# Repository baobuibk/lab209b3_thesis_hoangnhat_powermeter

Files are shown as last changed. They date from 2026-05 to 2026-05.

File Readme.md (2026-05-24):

# Power Meter Thesis — Project Overview

This repository contains the design, firmware, and dashboard for a low-cost embedded Power Meter developed as a thesis project.

Summary
- Objective: design and implement a compact, accurate power-meter device with real-time web monitoring and data logging.
- Scope: PCB designs (Altium), STM32 firmware (ADC sampling, signal processing, Modbus RS-485), and a Node.js dashboard for visualization.

Quick links
- Video demo: see [Video/Readme.md](Video/Readme.md)
- Dashboard: see [Dashboard](Dashboard)
- Firmware & source: see [Code](Code)
- Schematics & PCBs: see [Altium](Altium)

Getting started
- Build firmware: follow the CMake/Toolchain files in `Code/` and use an ARM toolchain (GCC `arm-none-eabi`).
- Run dashboard: in `Dashboard/` run `npm install` then `node server.js` to start the web UI.

Contributions & contact
- This repo contains thesis artifacts and reference implementations. Open an issue or contact the author for questions or collaboration.

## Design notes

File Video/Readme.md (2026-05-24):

# Video: Power Meter Demo

This folder contains a demo video for the Power Meter project. You can view or download the video from Dropbox:

- Dropbox link: https://www.dropbox.com/scl/fo/yewsmshvbbur9p4b5wdh0/ADq9qIouHD3EygoDCD3pfRs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

If the link does not open, copy-paste it into your browser.

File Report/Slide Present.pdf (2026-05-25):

### TRƯỜNG ĐẠI HỌC BÁCH KHOA THÀNH PHỐ HỒ CHÍ MINH KHOA ĐIỆN – ĐIỆN TỬ BỘ MÔN CUNG CẤP ĐIỆN

## ĐỒ ÁN TỐT NGHIỆP

### THIẾT KẾ THIẾT BỊ ĐỒNG HỒ ĐO ĐIỆN BA PHA

(Design of a Real-Time Monitoring Device for Three-Phase Electrical Parameters)

GVHD: ThS. Bùi Quốc Bảo
TS. Phạm Minh Đức
SVTH : Hoàng Sỹ Nhất 211915

TP. Hồ Chí Minh, 09/10/2025

Nội dung | FR

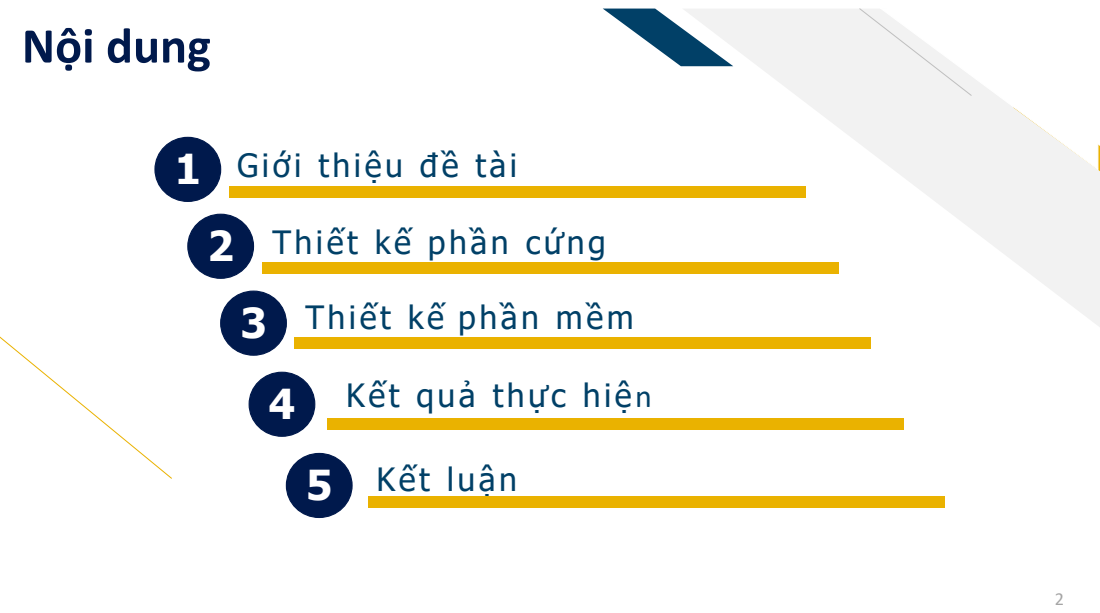
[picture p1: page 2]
Kết luận

Giới thiệu đề tài

Thiết kế phần cứng

Thiết kế phần mềm

Kết quả thực hiện

1. Giới thiệu đề tài | FR

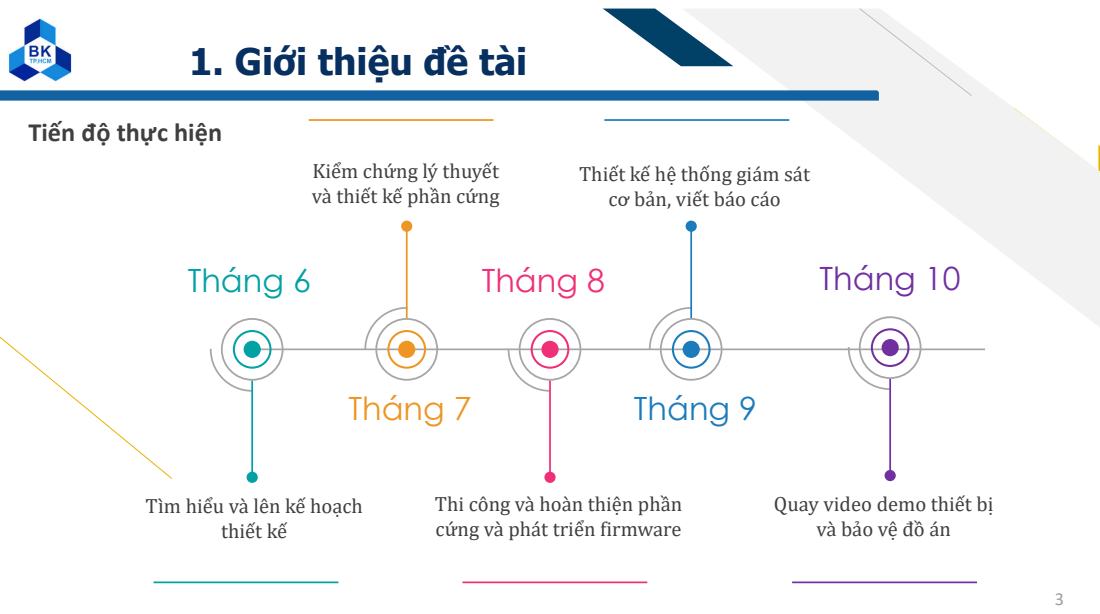
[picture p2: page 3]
Tháng 6; thiết kế; Tháng 7; Tháng 8; Tháng 9; Tháng 10

Tiến độ thực hiện

Kiểm chứng lý thuyết
và thiết kế phần cứng

Thiết kế hệ thống giám sát
cơ bản, viết báo cáo

Tìm hiểu và lên kế hoạch

Thi công và hoàn thiện phần
cứng và phát triển firmware

Quay video demo thiết bị
và bảo vệ đồ án

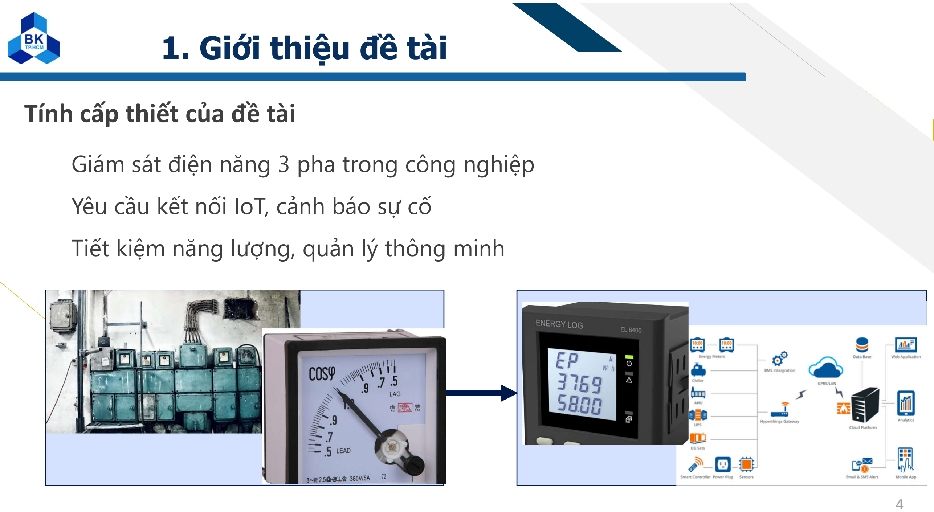
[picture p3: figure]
1. Giới thiệu đề tài; Tính cấp thiết của đề tài; Yêu cầu kết nối IoT, cảnh báo sự cố

Giám sát điện năng 3 pha trong công nghiệp

Tiết kiệm năng lượng, quản lý thông minh

1. Giới thiệu đề tài | FR

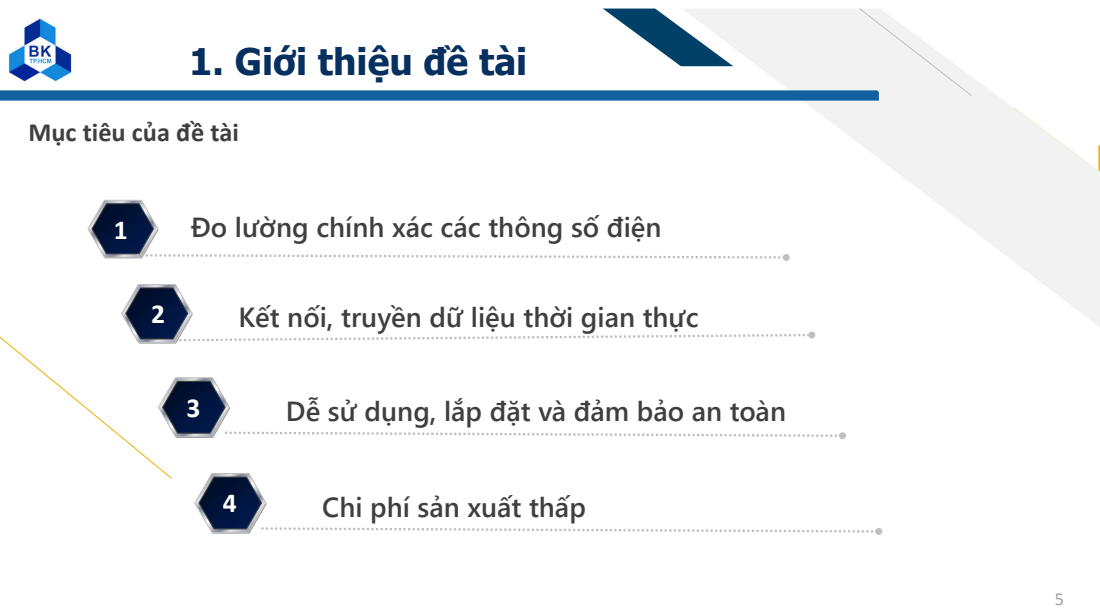
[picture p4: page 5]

Mục tiêu của đề tài

1 Đo lường chính xác các thông số điện

2 Kết nối, truyền dữ liệu thời gian thực

3 Dễ sử dụng, lắp đặt và đảm bảo an toàn

4 Chi phí sản xuất thấp

Bo thử nghiệm | Thiết bị đo phiên bản đầu tiên

2. Thiết kế phần cứng | FR

Sơ đồ khối tổng quát thiết bị

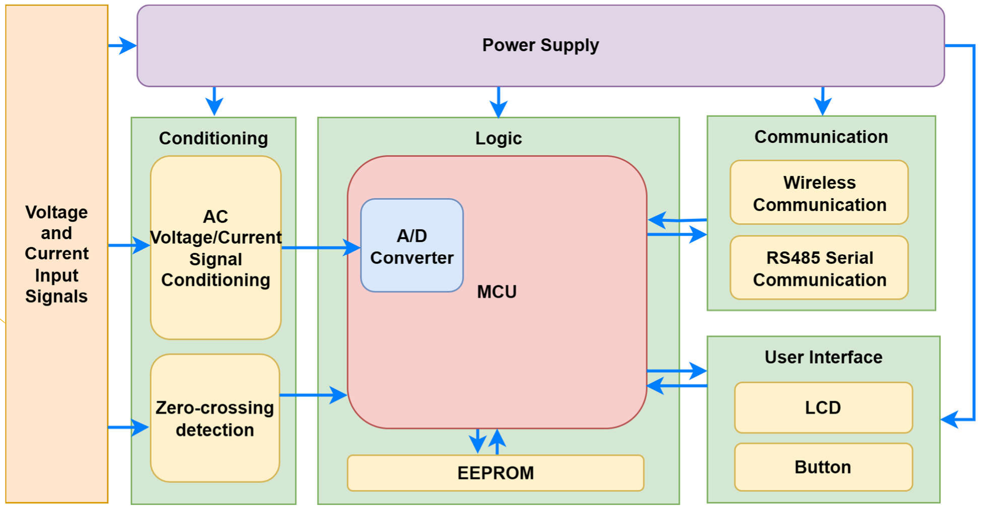
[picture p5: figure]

FR

## 2. Thiết kế phần cứng

8

Bo mạch dưới | Bo mạch trên

FR

## 2. Thiết kế phần cứng

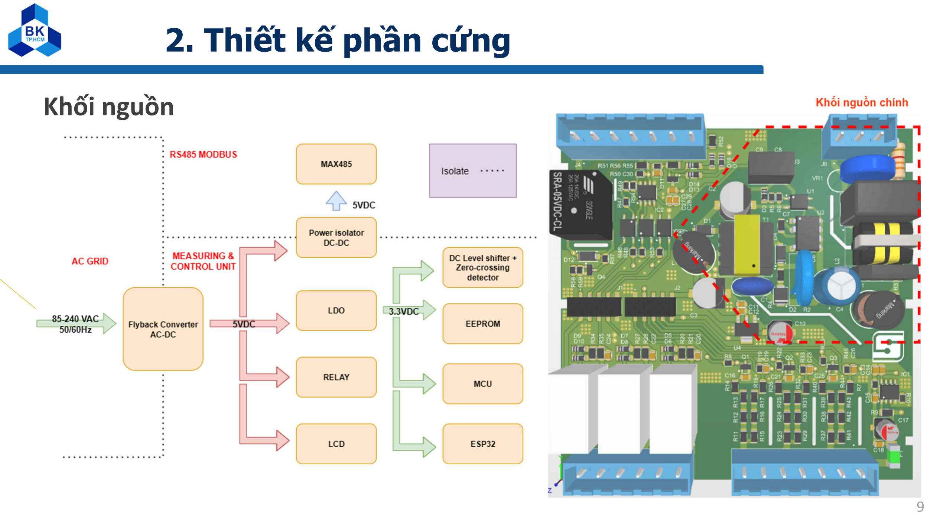
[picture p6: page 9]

9

### Khối nguồn

FR

## 2. Thiết kế phần cứng

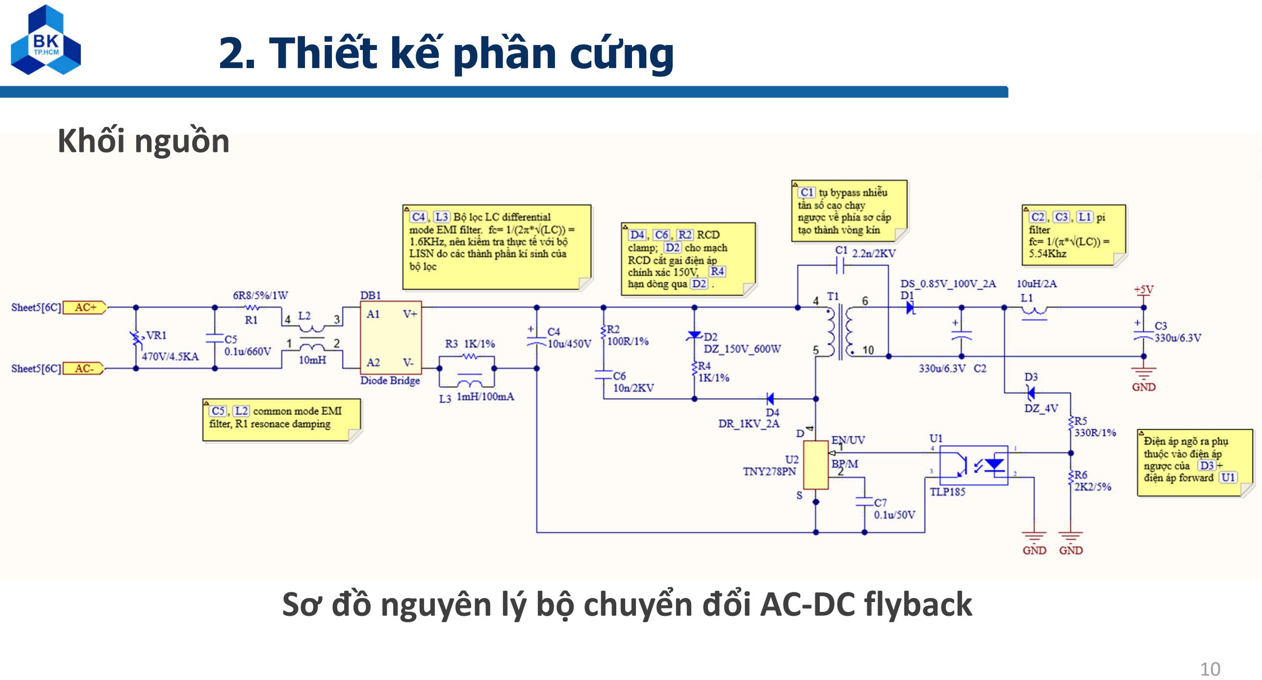
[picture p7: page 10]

10

### Khối nguồn

### Sơ đồ nguyên lý bộ chuyển đổi AC-DC flyback

FR

## 2. Thiết kế phần cứng

11

### Khối xử lý điện áp và dòng

Sơ đồ tín hiệu điện áp và tín hiệu sau xử lý

FR

## 2. Thiết kế phần cứng

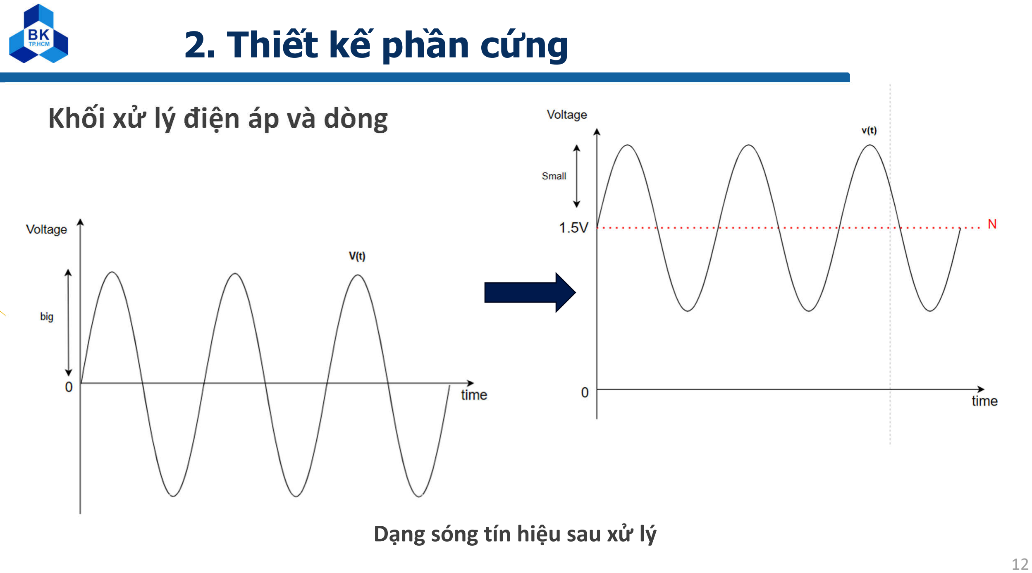
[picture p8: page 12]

12

### Khối xử lý điện áp và dòng

Dạng sóng tín hiệu sau xử lý

FR

## 2. Thiết kế phần cứng

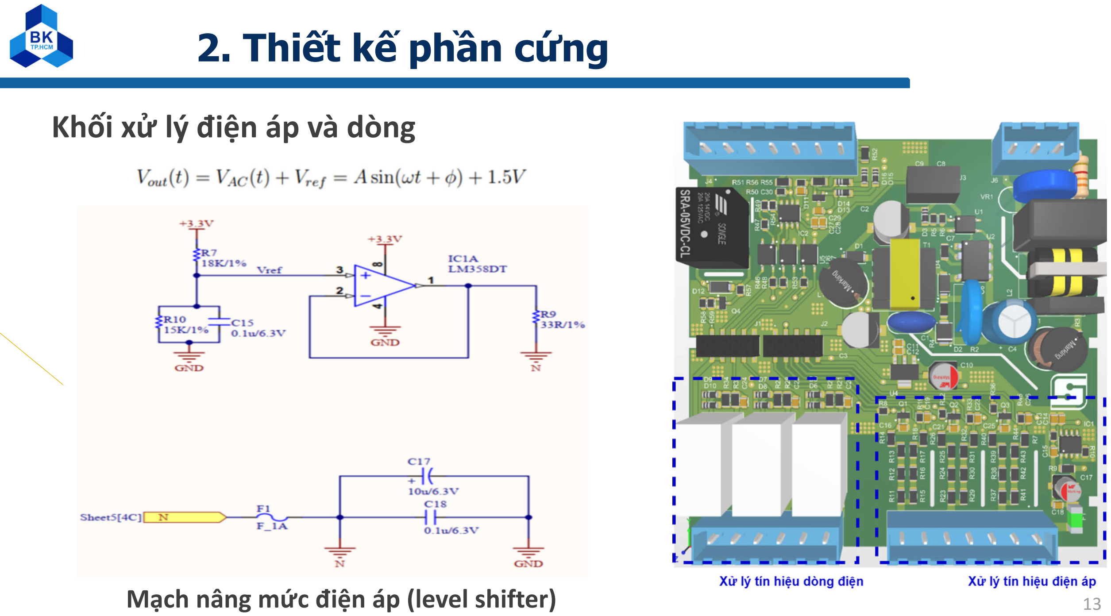
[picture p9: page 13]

13

### Khối xử lý điện áp và dòng

Mạch nâng mức điện áp (level shifter)

FR

## 2. Thiết kế phần cứng

14

### Khối xử lý điện áp và dòng

Mạch xử lý tín hiệu dòng điện

FR

## 2. Thiết kế phần cứng

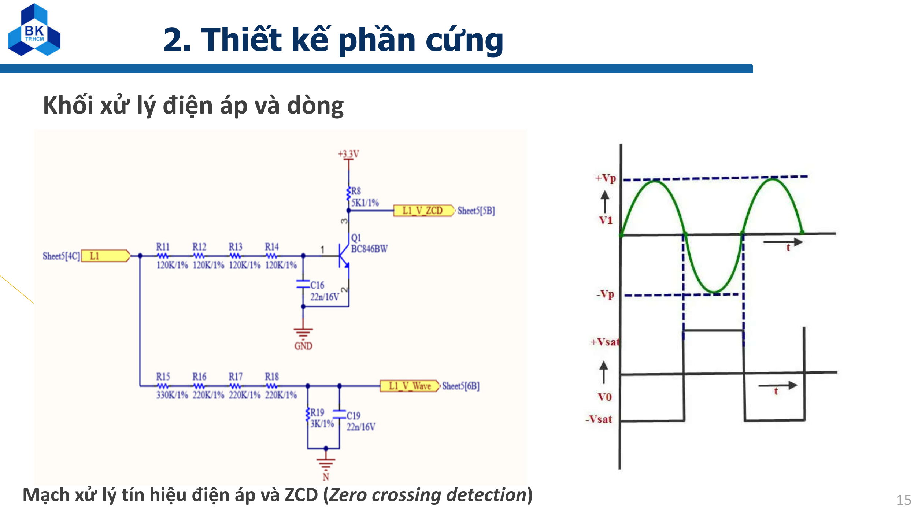
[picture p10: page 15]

15

### Khối xử lý điện áp và dòng

Mạch xử lý tín hiệu điện áp và ZCD (Zero crossing detection)

FR

## 2. Thiết kế phần cứng

16

### Khối giao tiếp RS485 và Relay

FR

## 2. Thiết kế phần cứng

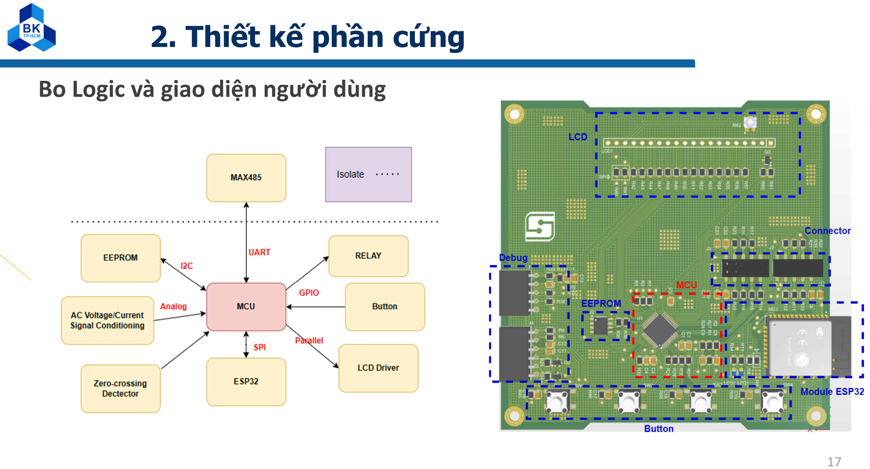
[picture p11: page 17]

17

### Bo Logic và giao diện người dùng

FR

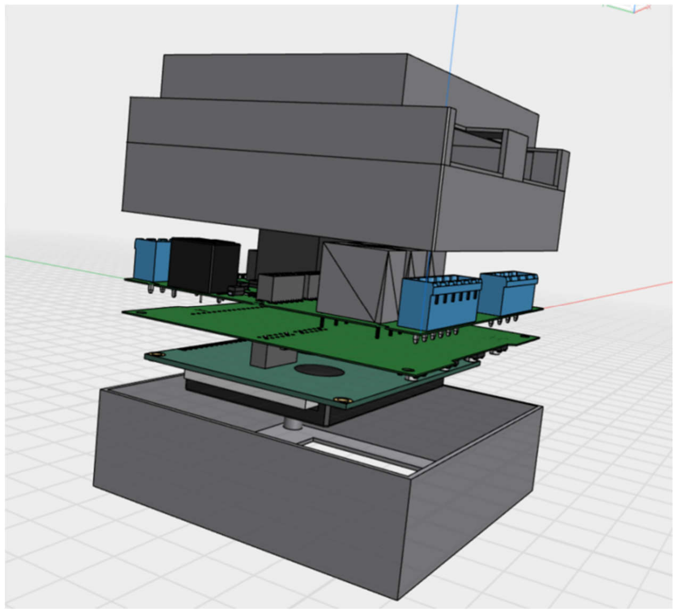
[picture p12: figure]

18

## 2. Thiết kế phần cứng

### Thiết kế vỏ hộp

AC Grid → STM32 → ESP32 → MQTT Broker → Web Dashboard.

FR

## 3. Thiết kế phần mềm

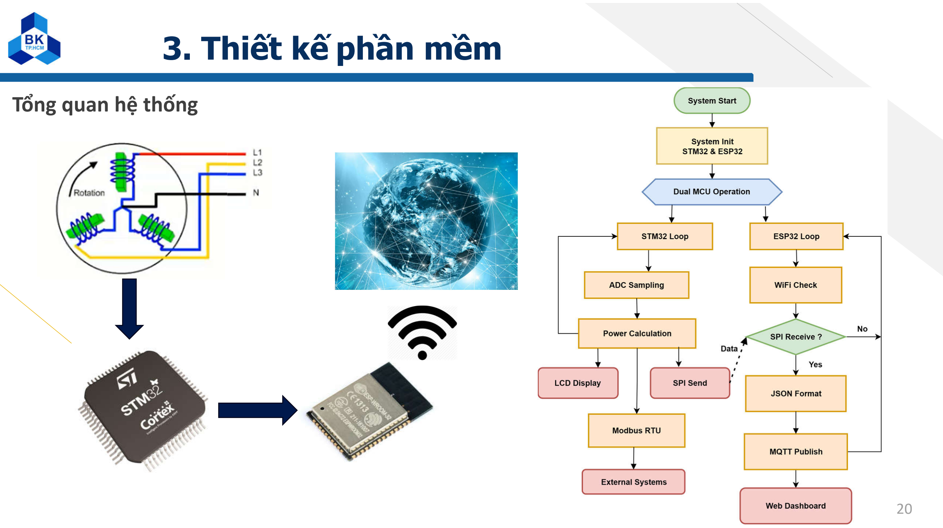
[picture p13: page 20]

20

Tổng quan hệ thống

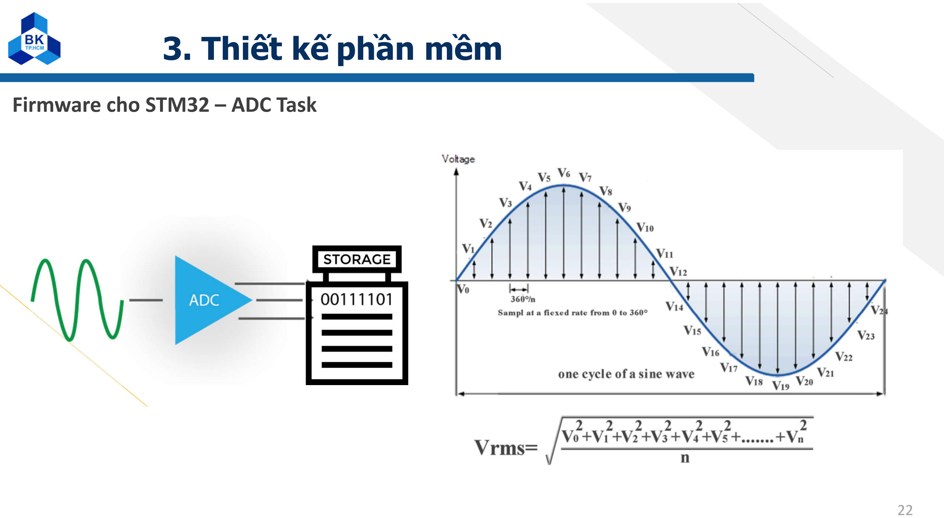
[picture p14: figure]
3. Thiết kế phần mềm; Firmware cho STM32 – ADC Task

FR

## 3. Thiết kế phần mềm

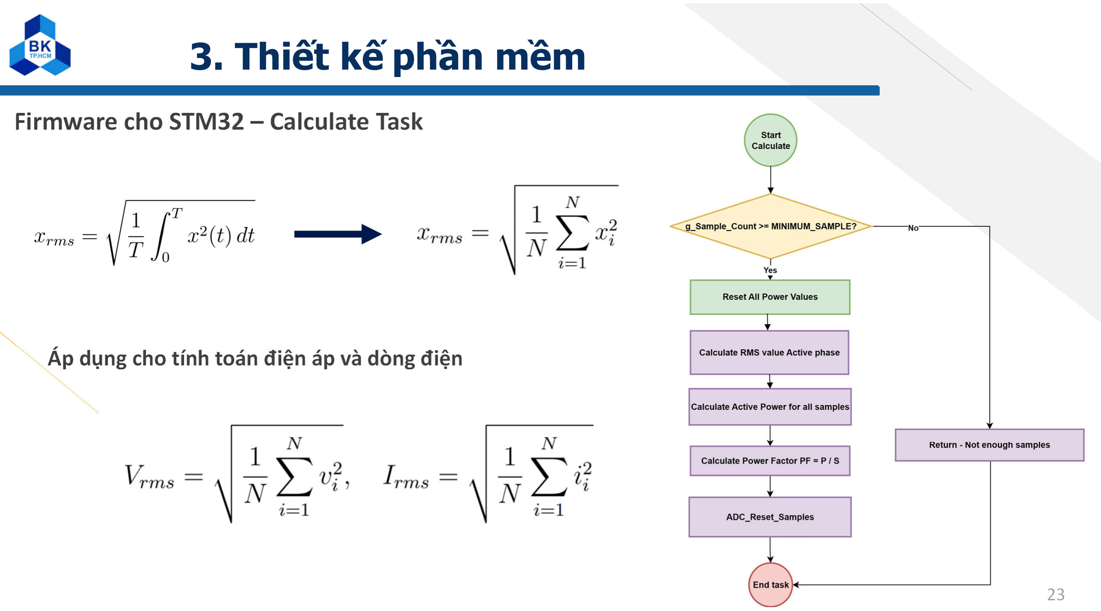
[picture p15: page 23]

23

Firmware cho STM32 – Calculate Task

Áp dụng cho tính toán điện áp và dòng điện

FR

## 3. Thiết kế phần mềm

24

Firmware cho STM32 – Calculate Task

Tính toán công suất

FR

## 3. Thiết kế phần mềm

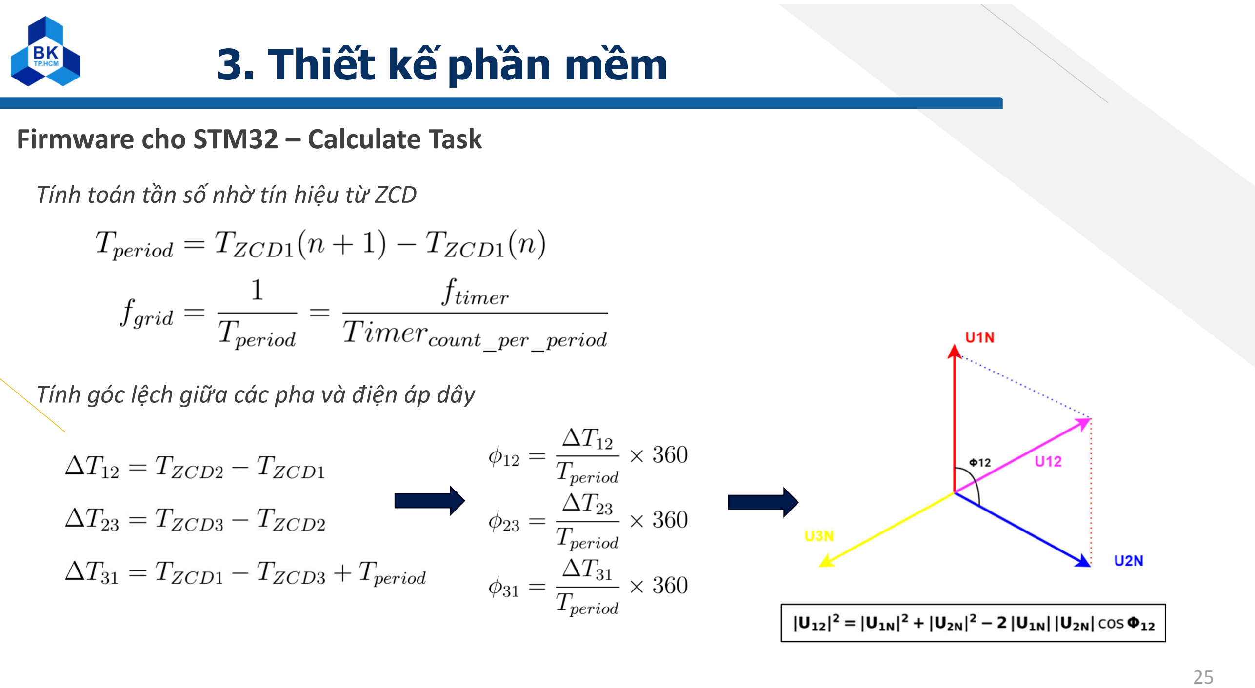
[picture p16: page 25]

25

Firmware cho STM32 – Calculate Task

Tính góc lệch giữa các pha và điện áp dây

Tính toán tần số nhờ tín hiệu từ ZCD

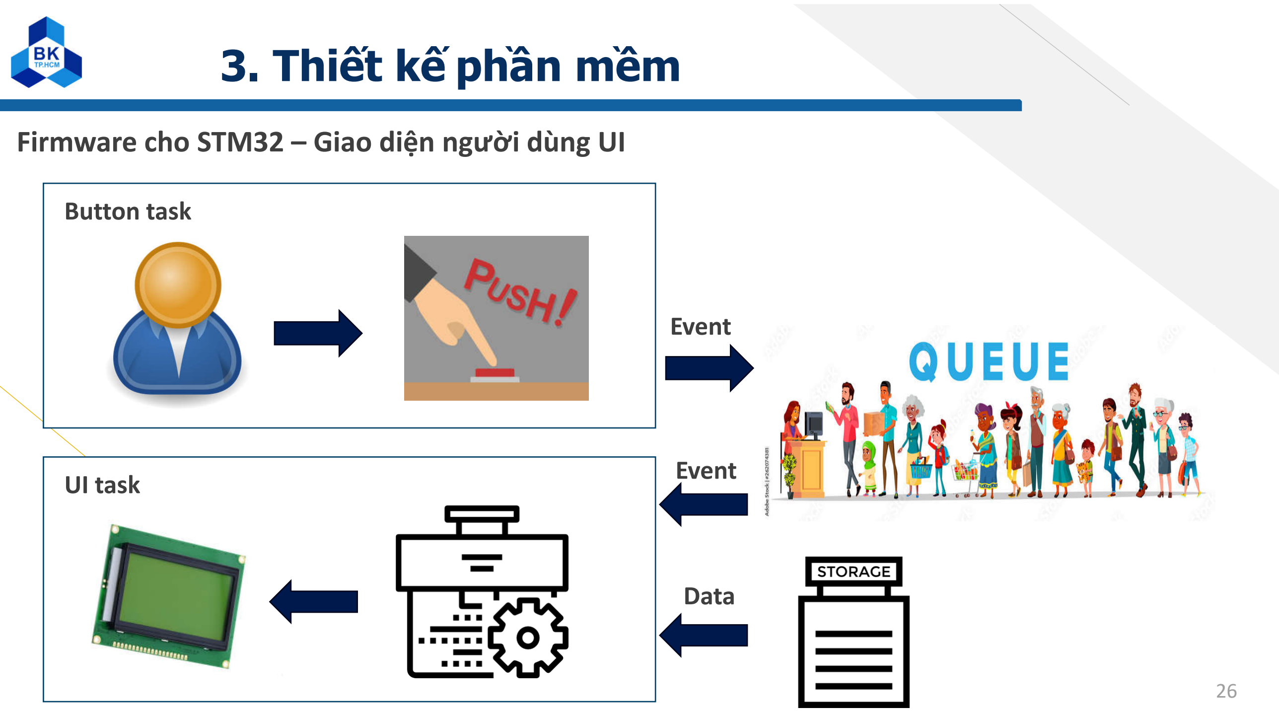
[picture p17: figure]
3. Thiết kế phần mềm; Button task; UI task; Event; Data

Firmware cho STM32 – Giao diện người dùng UI

FR

## 3. Thiết kế phần mềm

27

Firmware cho STM32 – Giao tiếp SPI với ESP32

Cấu trúc gói tin SPI Data

Data

FR

## 3. Thiết kế phần mềm

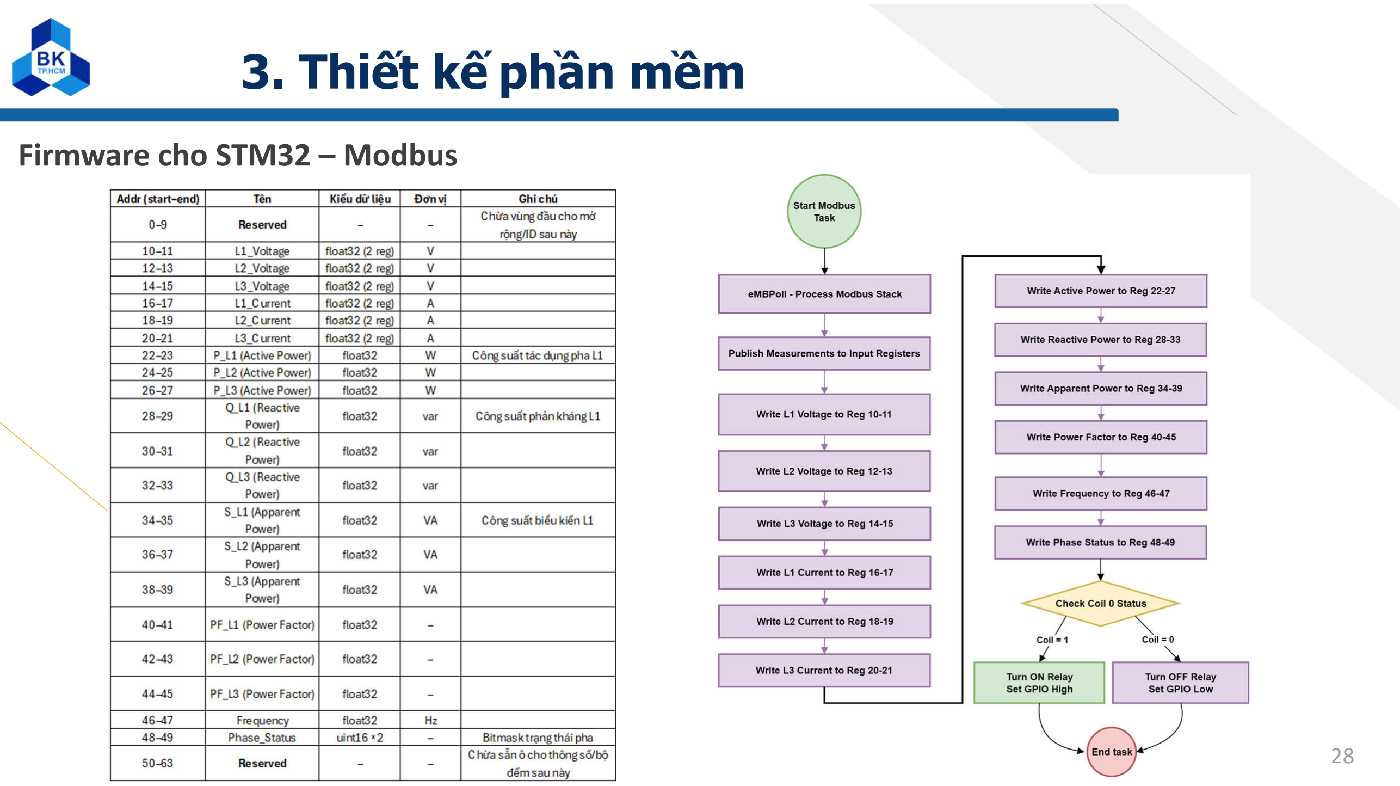
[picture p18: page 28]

28

Firmware cho STM32 – Modbus

FR

## 3. Thiết kế phần mềm

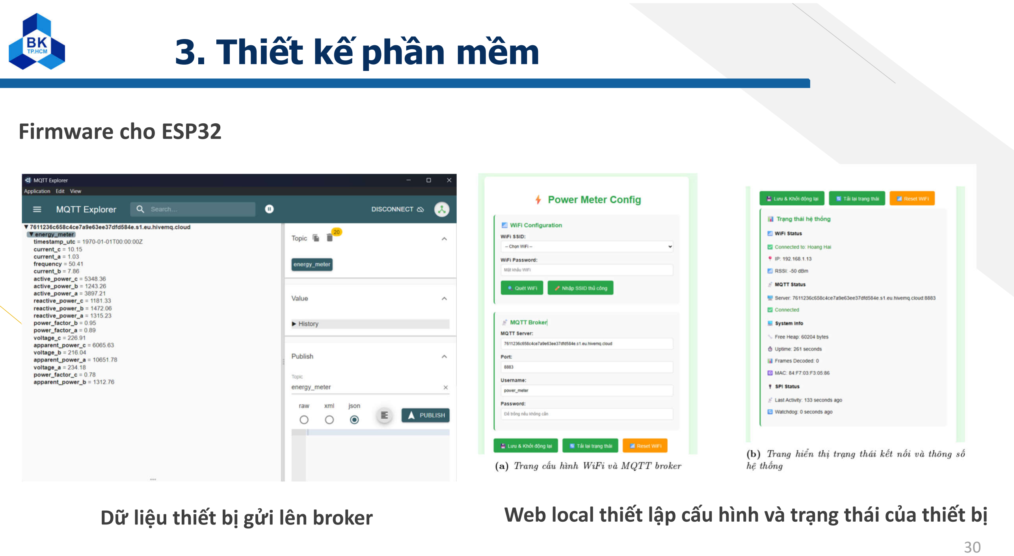
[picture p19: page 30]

30

Dữ liệu thiết bị gửi lên broker | Web local thiết lập cấu hình và trạng thái của thiết bị

Firmware cho ESP32

FR

## 3. Thiết kế phần mềm

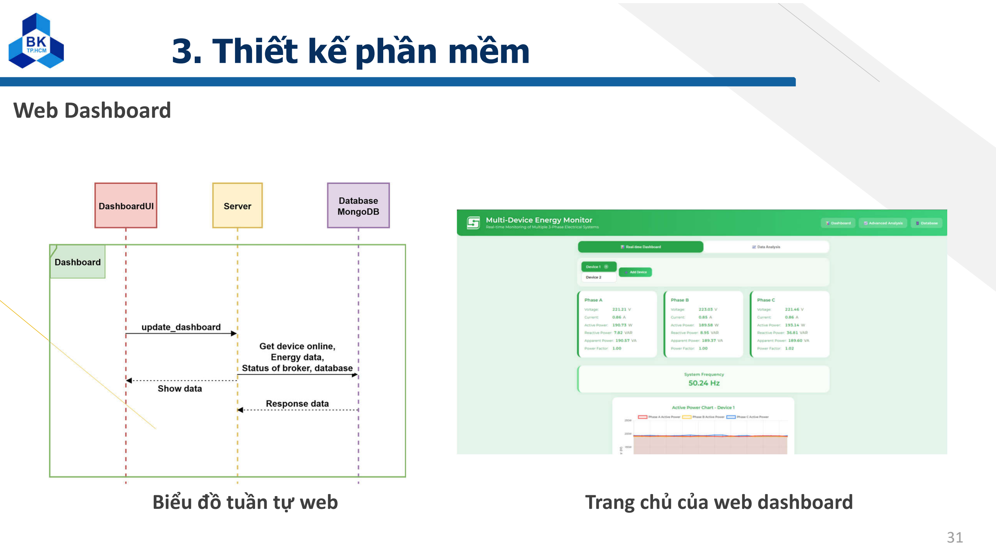
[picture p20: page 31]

31

Web Dashboard

Biểu đồ tuần tự web | Trang chủ của web dashboard

FR

## 4. Kết quả thực hiện

32

Kết quả thi công bo mạch | Kết quả thi công lắp ráp thiết bị

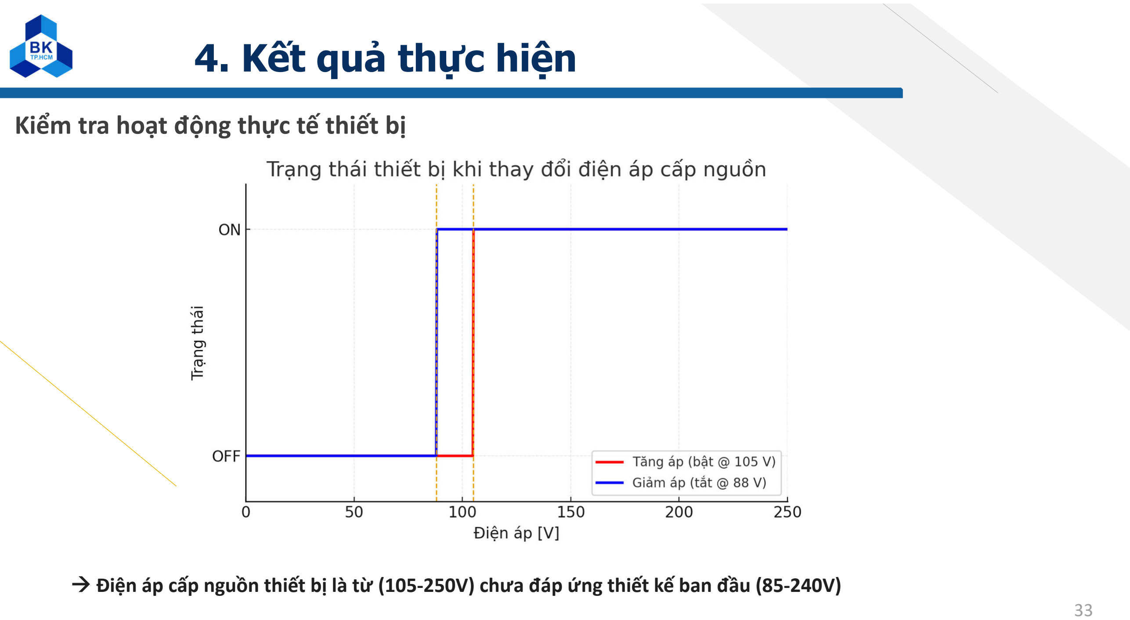
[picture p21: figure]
4. Kết quả thực hiện; Kiểm tra hoạt động thực tế thiết bị

→ Điện áp cấp nguồn thiết bị là từ (105-250V) chưa đáp ứng thiết kế ban đầu (85-240V)

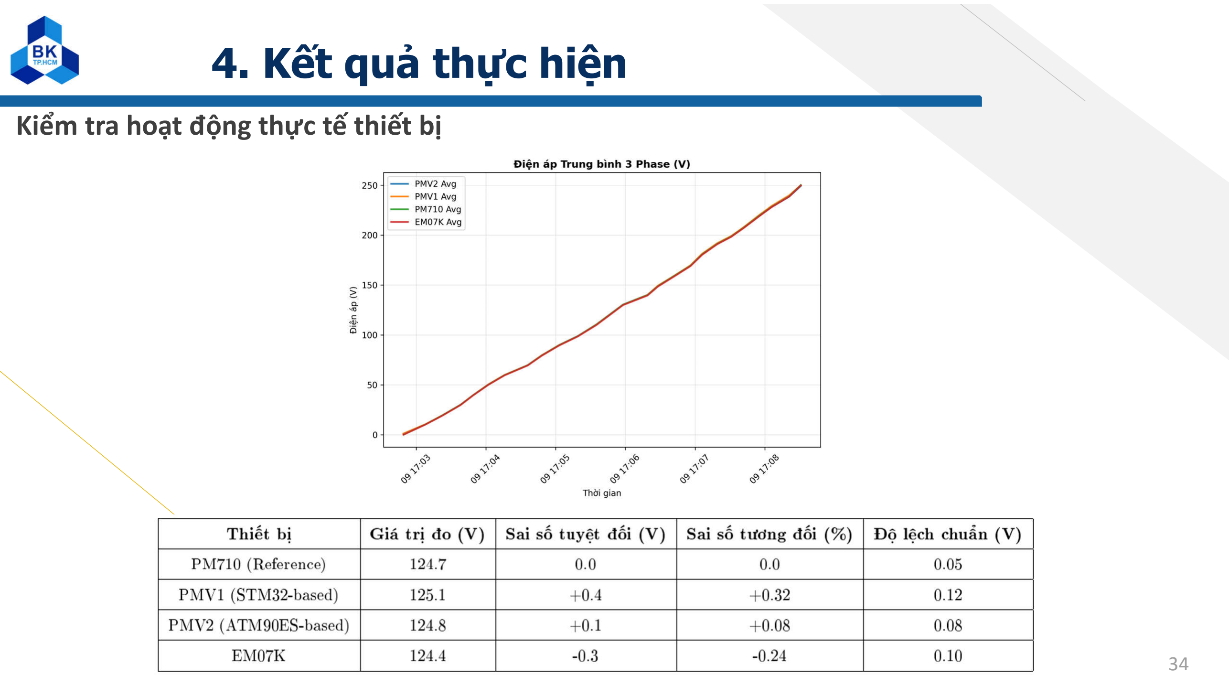
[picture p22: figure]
4. Kết quả thực hiện; Kiểm tra hoạt động thực tế thiết bị

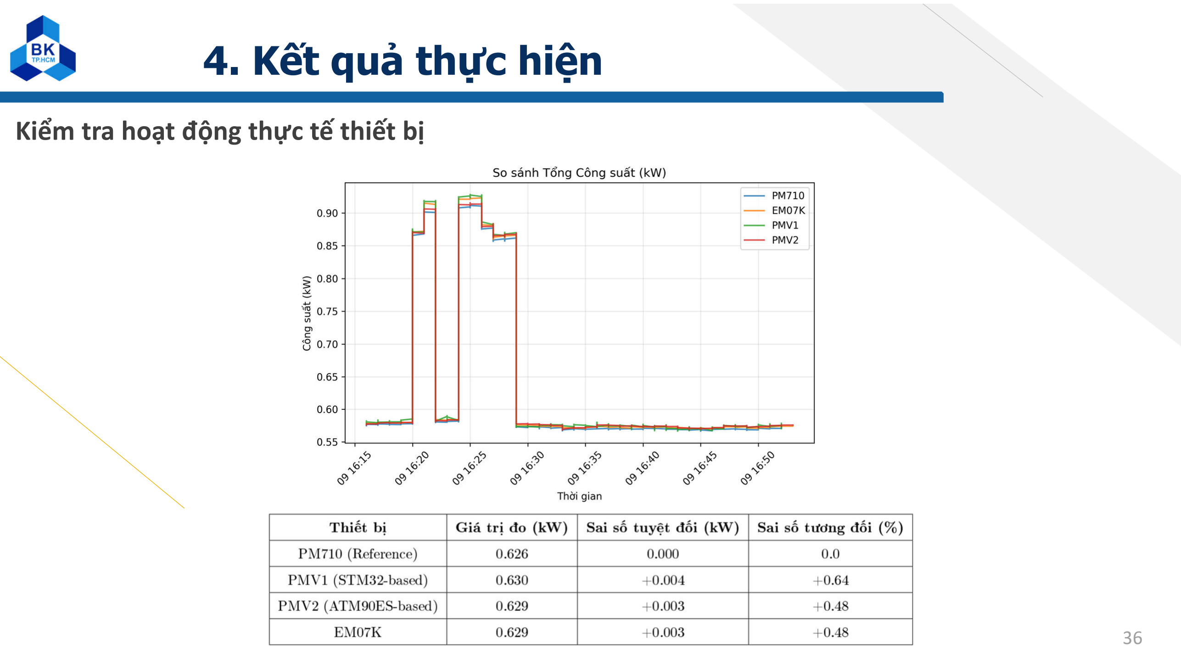
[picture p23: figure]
4. Kết quả thực hiện; Kiểm tra hoạt động thực tế thiết bị

- Truyền thông đa giao thức (Modbus RTU + MQTT)
- Tiết kiệm chi phí so với mua thiết bị cùng chức năng trên thị trường
- Linh động trong việc chọn nền tảng lưu trữ đám mây.

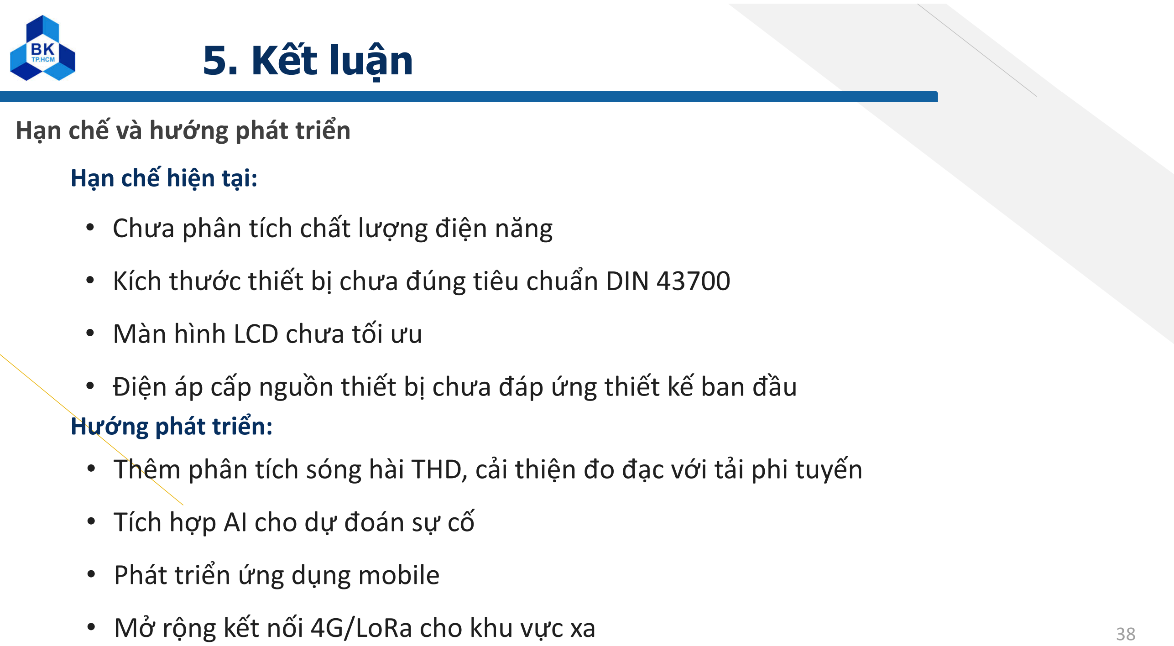
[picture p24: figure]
5. Kết luận; Hạn chế và hướng phát triển; Hạn chế hiện tại:; • Chưa phân tích chất lượng điện năng; • Màn hình LCD chưa tối ưu; • Tích hợp AI cho dự đoán sự cố; • Phát triển ứng dụng mobile; Hướng phát triển:

- Kích thước thiết bị chưa đúng tiêu chuẩn DIN 43700
- Điện áp cấp nguồn thiết bị chưa đáp ứng thiết kế ban đầu
- Thêm phân tích sóng hài THD, cải thiện đo đạc với tải phi tuyến
- Mở rộng kết nối 4G/LoRa cho khu vực xa

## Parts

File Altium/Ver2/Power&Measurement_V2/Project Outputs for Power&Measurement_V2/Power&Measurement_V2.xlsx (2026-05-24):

Comment | Description | Designator | Footprint | LibRef | Quantity
220u/6.3V |  | C1 | CAP-ALU-SMD-6.3x7.7x2.2 | CAP_POLAR | 1
0.1u/660V |  | C2 | CAPRR1500W60L1750T900H1600 | CAP_SMD | 1
100u/6.3V |  | C3 | CAP-ALU-SMD-6.3x7.7x2.2 | CAP_POLAR | 1
10u/6.3V |  | C4, C6, C9, C10 | CAP_C_2012X110 | CAP_SMD | 4
0.1u/6.3V |  | C5, C7, C11 | CAP_C_2012X110 | CAP_SMD | 3
4.7u/6.3V |  | C8 | CAP_C_2012X110 | CAP_SMD | 1
0.1n/16V |  | C12, C13 | CAP_C_2012X110 | CAP_SMD | 2
0.1u/16V |  | C14, C15, C16, C18, C23 | CAP_C_2012X110 | CAP_SMD | 5
10u/16V |  | C17 | CAP_C_2012X110 | CAP_SMD | 1
4.7u/16V |  | C19 | CAP_C_2012X110 | CAP_SMD | 1
18n/16V |  | C20, C21, C22, C24, C25, C26, C27, C28, C29, C30, C31, C32 | CAP_C_2012X110 | CAP_SMD | 12
ZHT107(5A/2.5mA) | C5183046 | CT1, CT2, CT3 | ZHT107 | ZHT-107 | 3
DR_1KV_1A | Default Diode | D1 | DIOM5025X26N | Diode | 1
SM712-02HTG | TVS Diode, SM712 Series, 31V Clamp, 600W Peak Pulse, Surface Mount, SOT23-3 | Littelfuse SM712-02HTG | D2 | SOT95P237X112-3N | SM712-02HTG | 1
DZ_12V | Zenner | D3, D4 | LL-34 | DIODE Zener | 2
DZ_7V | Zenner | D5, D6 | LL-34 | DIODE Zener | 2
F_1A | Fuse | F1 | FUSC6127X294N | Fuse | 1
MAX485 | RS232 - RS485 (Same sn75176) | IC1 | SOIC-8 | MAX485 | 1
TBP01R2-508-06BE | 2~24 Ð¿Ð¾Ð»ÑŽÑ Ð°, Ð¿Ð¾Ð´ÐºÐ»ÑŽÑ‡Ð°ÐµÐ¼Ñ‹Ð¹, Ð²ÐµÑ€Ñ‚Ð¸ÐºÐ°Ð»ÑŒÐ½Ñ‹Ð¹, ÑˆÐ°Ð³ 5,08, ÐºÐ»ÐµÐ¼Ð¼Ð½Ñ‹Ð¹ Ð±Ð»Ð¾Ðº | J1 | CUI_TBP01R2-508-06BE | TBP01R2-508-06BE | 1
TBP01R2-508-07BE | 2~24 Poles, Pluggable, Receptacle, Vertical, 5.08 Pitch, Terminal Block Connector | J2 | CUI_TBP01R2-508-07BE | TBP01R2-508-07BE | 1
TBP05R2-762-04BE | 2~24 Poles, Pluggable, Receptacle, Vertical, 7.62 Pitch, Terminal Block Connector | J3 | CUI_TBP05R2-762-04BE | TBP05R2-762-04BE | 1
TBP01R2-508-03BE | 2~24 Poles, Pluggable, Receptacle, Vertical, 5.08 Pitch, Terminal Block Connector | J4 | CUI_TBP01R2-508-03BE | TBP01R2-508-03BE | 1
SSM-106-S-DV | Connector | J5, J6 | SSM-106-XXX-DV-BE | SSM-106-S-DV | 2
SRA-05VDC-CL |  | K1 | RELAY_SRA-05VDC-CL | SRA-05VDC-CL | 1
10mH |  | L1 | UU98LFH142LF | L-DIP-2 | 1
LED |  | LED1, LED2, LED3, LED4 | LED-0805-Blue | LED SMD | 4
HLK-5M05 | AC DC 220V to 5V 5W 5Watt Isolated Switching Step-Down Power Supply Module Converter | PS1 | CONV_HLK-5M05 | HLK-5M05 | 1
BC817W |  | Q1 | SOT-323 | BJT_NPN | 1
6R8/5%/1W | Resistor | R1 | RES-1W | Res-SMD | 1
330R/1% | Resistor | R2, R7, R9 | RES_C_2012X65 | Res-SMD | 3
0R/1% | Resistor | R3 | RES_C_2012X65 | Res-SMD | 1
560R/5% | Resistor | R4, R8, R10 | RES_C_2012X65 | Res-SMD | 3
1K/1% | Resistor | R5, R16, R19, R21, R29, R30, R36, R44, R45, R53, R54, R62, R63 | RES_C_2012X65 | Res-SMD | 13
5.1K/1% | Resistor | R6, R20, R22, R23, R24, R25 | RES_C_2012X65 | Res-SMD | 6
2K2/5% | Resistor | R11, R15 | RES_C_2012X65 | Res-SMD | 2
10R/1% | Resistor | R12, R14 | RES_C_3216X70 | Res-SMD | 2
120R/1% | Resistor | R13 | RES_C_3216X70 | Res-SMD | 1
2.4R/1% | Resistor | R17, R18, R26, R27, R32, R34 | RES_C_2012X65 | Res-SMD | 6
750R/1% | Resistor | R28, R31, R33, R35 | RES_C_2012X65 | Res-SMD | 4
240K/1% | Resistor | R37, R38, R39, R40, R41, R42, R43, R46, R47, R48, R49, R50, R51, R52, R55, R56, R57, R58, R59, R60, R61 | RES_C_2012X65 | Res-SMD | 21
LM1117-3.3V | 800mA Low-Dropout Linear Regulator | U1 | SOT230P700X180-4N | LM1117 | 1
B0505S |  | U2 | B0505S-1W | B0505S | 1
TLP185 | Single Opto | U3, U4, U5 | SOP254P700X220-4N | TLP185 | 3
ATM90E32AS-AU-R | IC ENERGY METER 1.8V/3V 48TQFP | U6 | TSQFP50P900X900X120-48N | ATM90E32AS-AU-R | 1
470V/4.5KA | MOV-14D471K, Varistors 470V 14mm | VR1 | B72214P2301K101 | Varistor | 1
16.384Mhz | Crystal, 32.768 KHz, -40 to 85 degC, 3.2 x 1.5 x 0.9 mm SMD | X1 | XT2-SMD | XT2 | 1

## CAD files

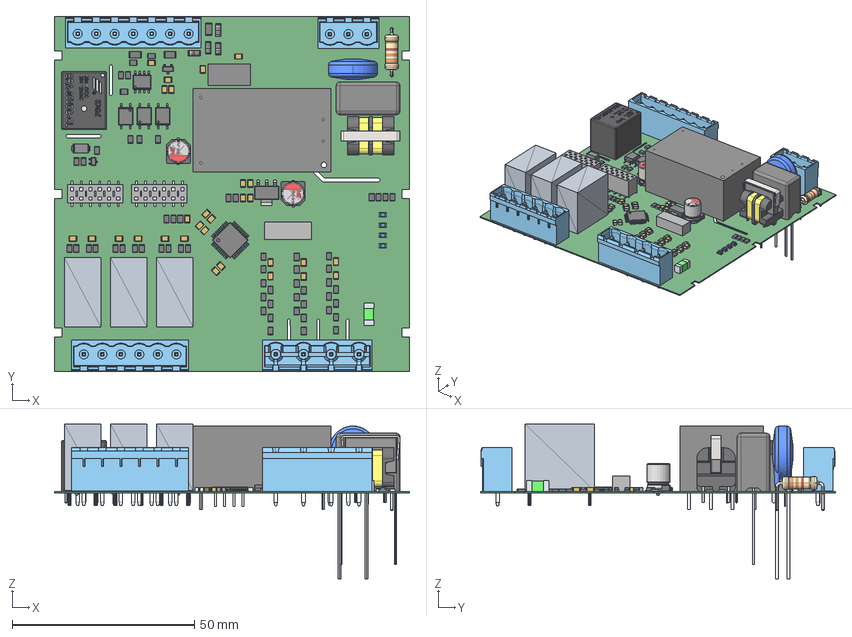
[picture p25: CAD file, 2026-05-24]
Altium/Ver2/Power&Measurement_V2/BotV1.step
97.5 x 97.5 x 42.5 mm
SSM-106-S-DV-A_body x 2
C-137-01-S6 x 2
Extruded x 3
Leader x 74
B_S-1WR3
Lead x 3
Tab
Mid Body x 62
Mark x 62
User Library-Res50-Axial 0_5W-3_3K
User Library-led_0805-blue x 4
User Library-UF9_8
term1
term2
1SMA4742
leftPin x 4
rightPin x 4
ZHT107 x 3
capicitor_6.3x7.7x2.2 x 2
Base_Φ6_3Capacitor x 2
ECQUAAF334K

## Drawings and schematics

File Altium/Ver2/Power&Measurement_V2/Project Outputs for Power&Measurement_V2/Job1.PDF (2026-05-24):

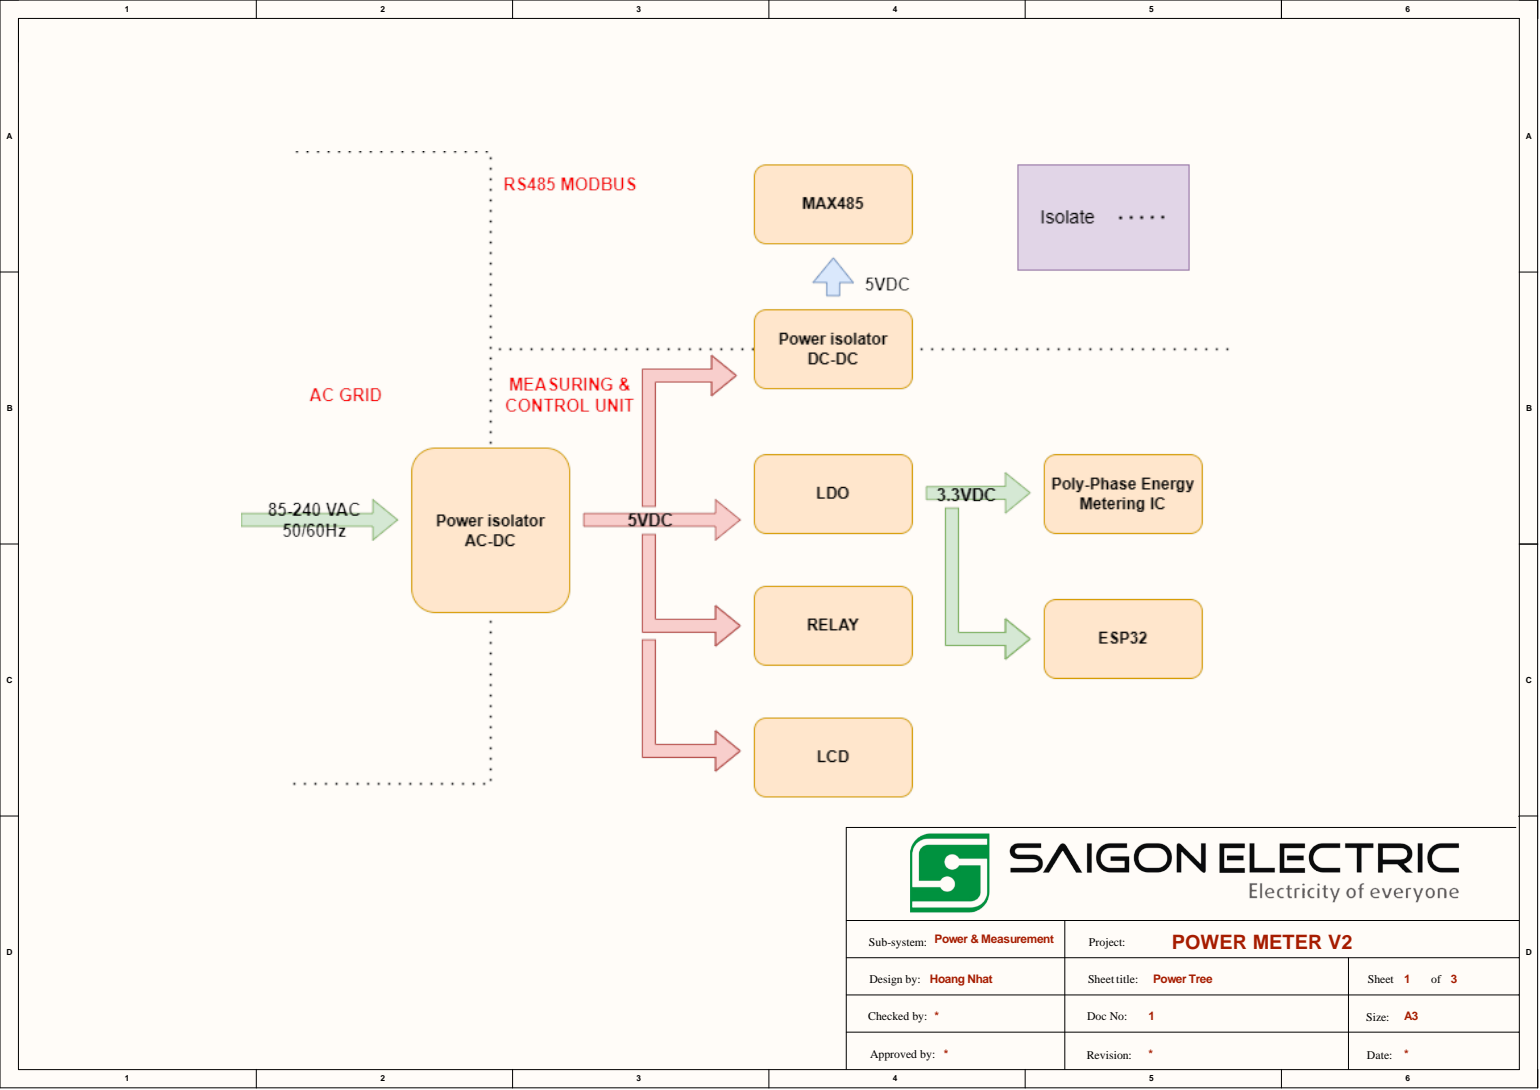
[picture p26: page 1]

Sub-system: Power & Measurement | Project: POWER METER V2

Design by: Hoang Nhat | Sheet title: Power Tree | Sheet 1 3 of

Checked by: | Doc No: | Size: A3

Approved by: | Revision: * | Date: *

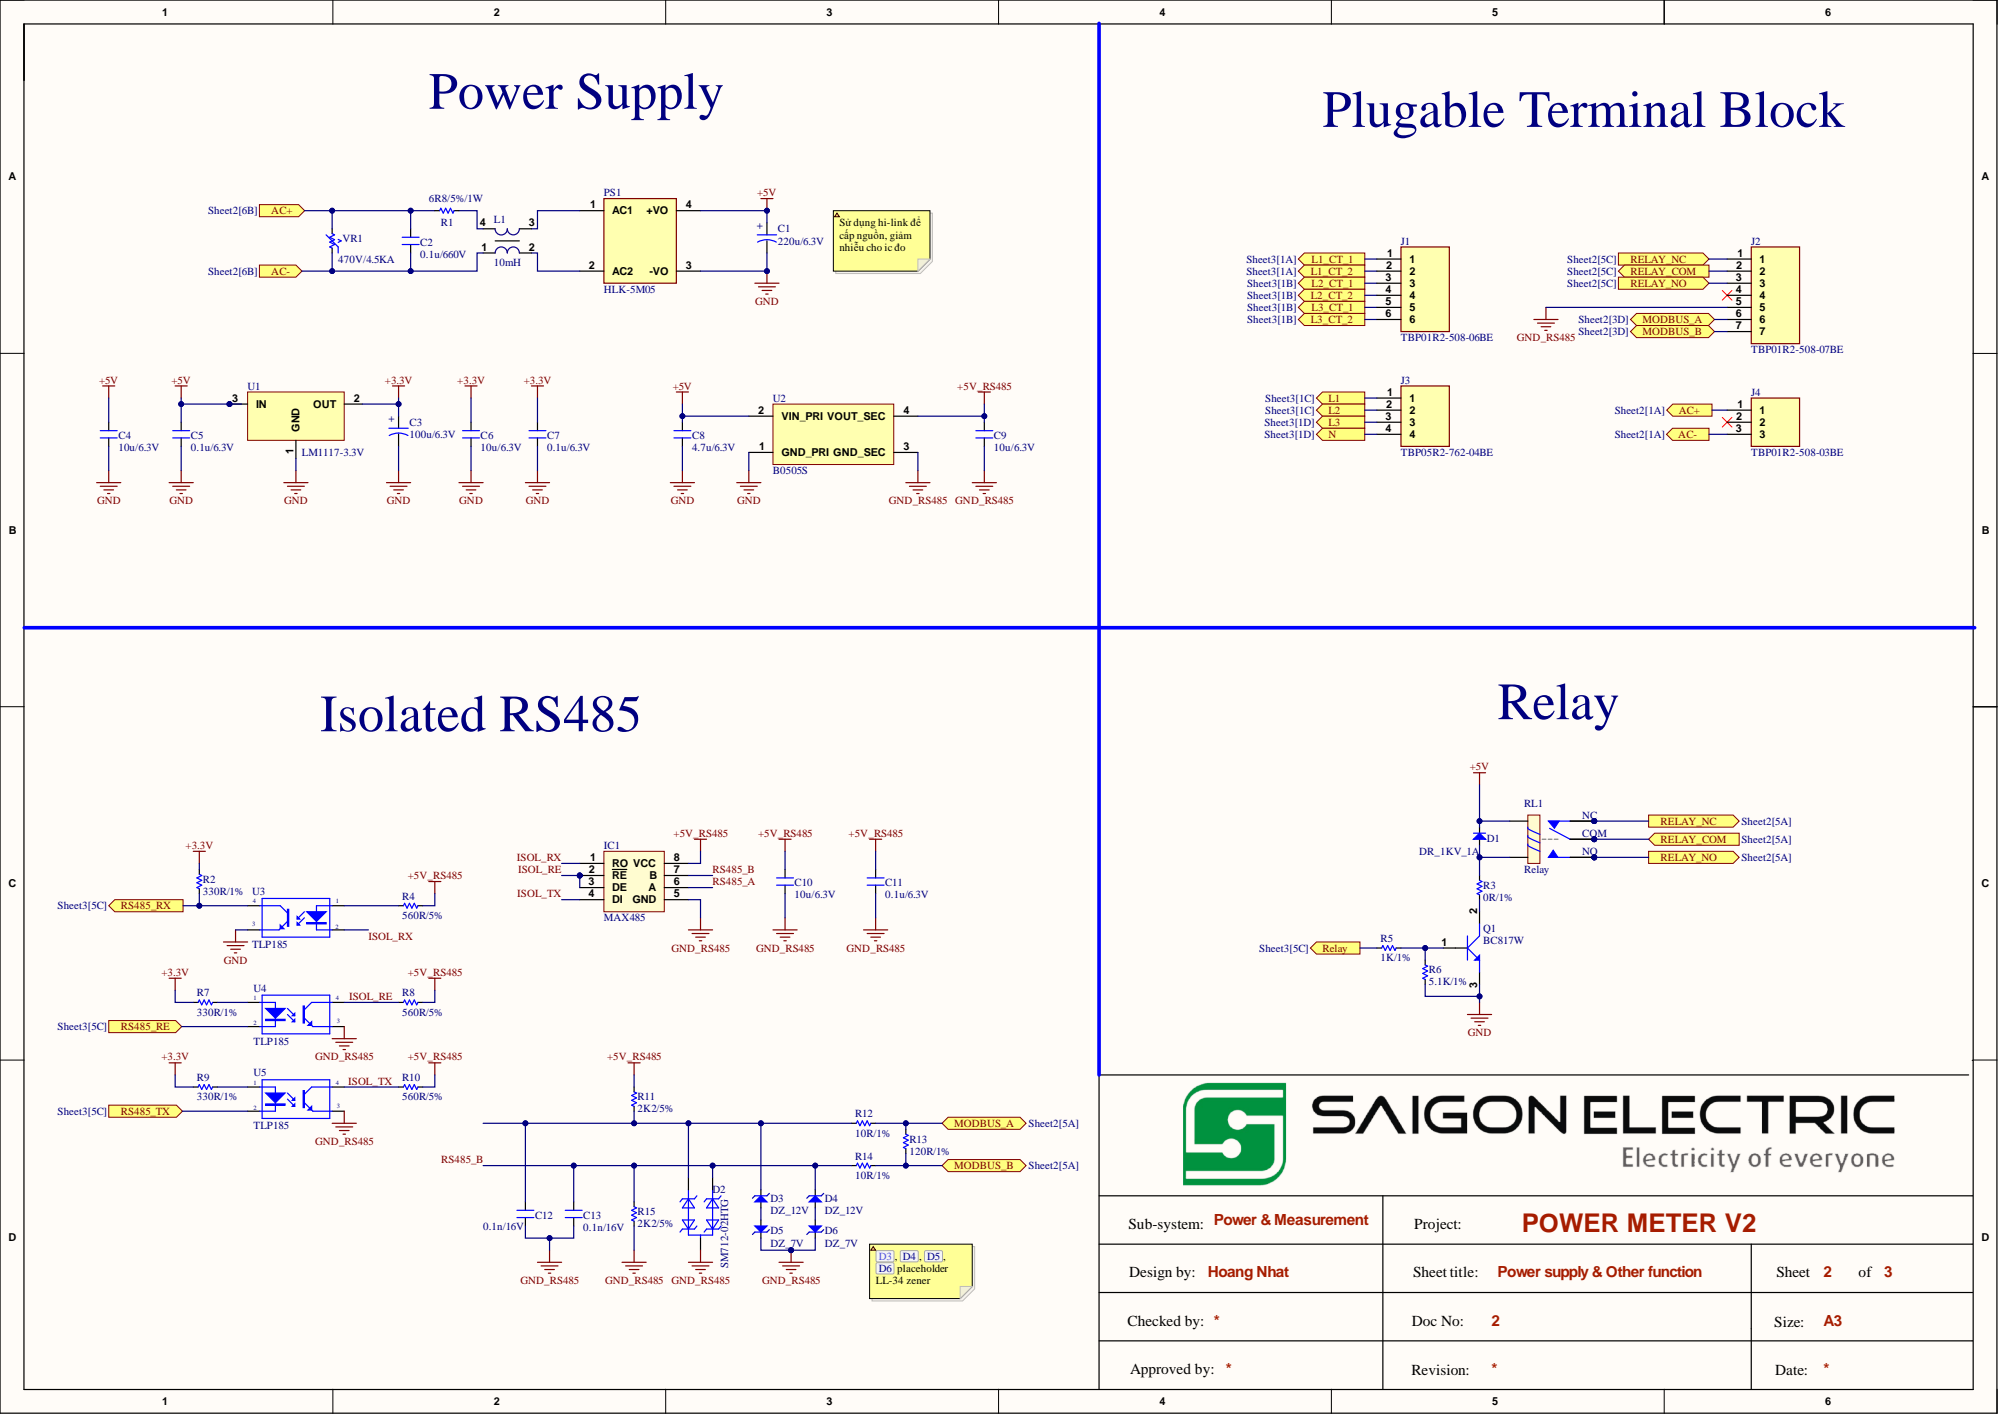
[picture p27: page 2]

Sử dụng hi-link để
cấp nguồn, giảm
nhiễu cho ic đo

Sub-system: Power & Measurement | Project: POWER METER V2

Design by: Hoang Nhat | Sheet title: Power supply & Other function | Sheet 2 3 of

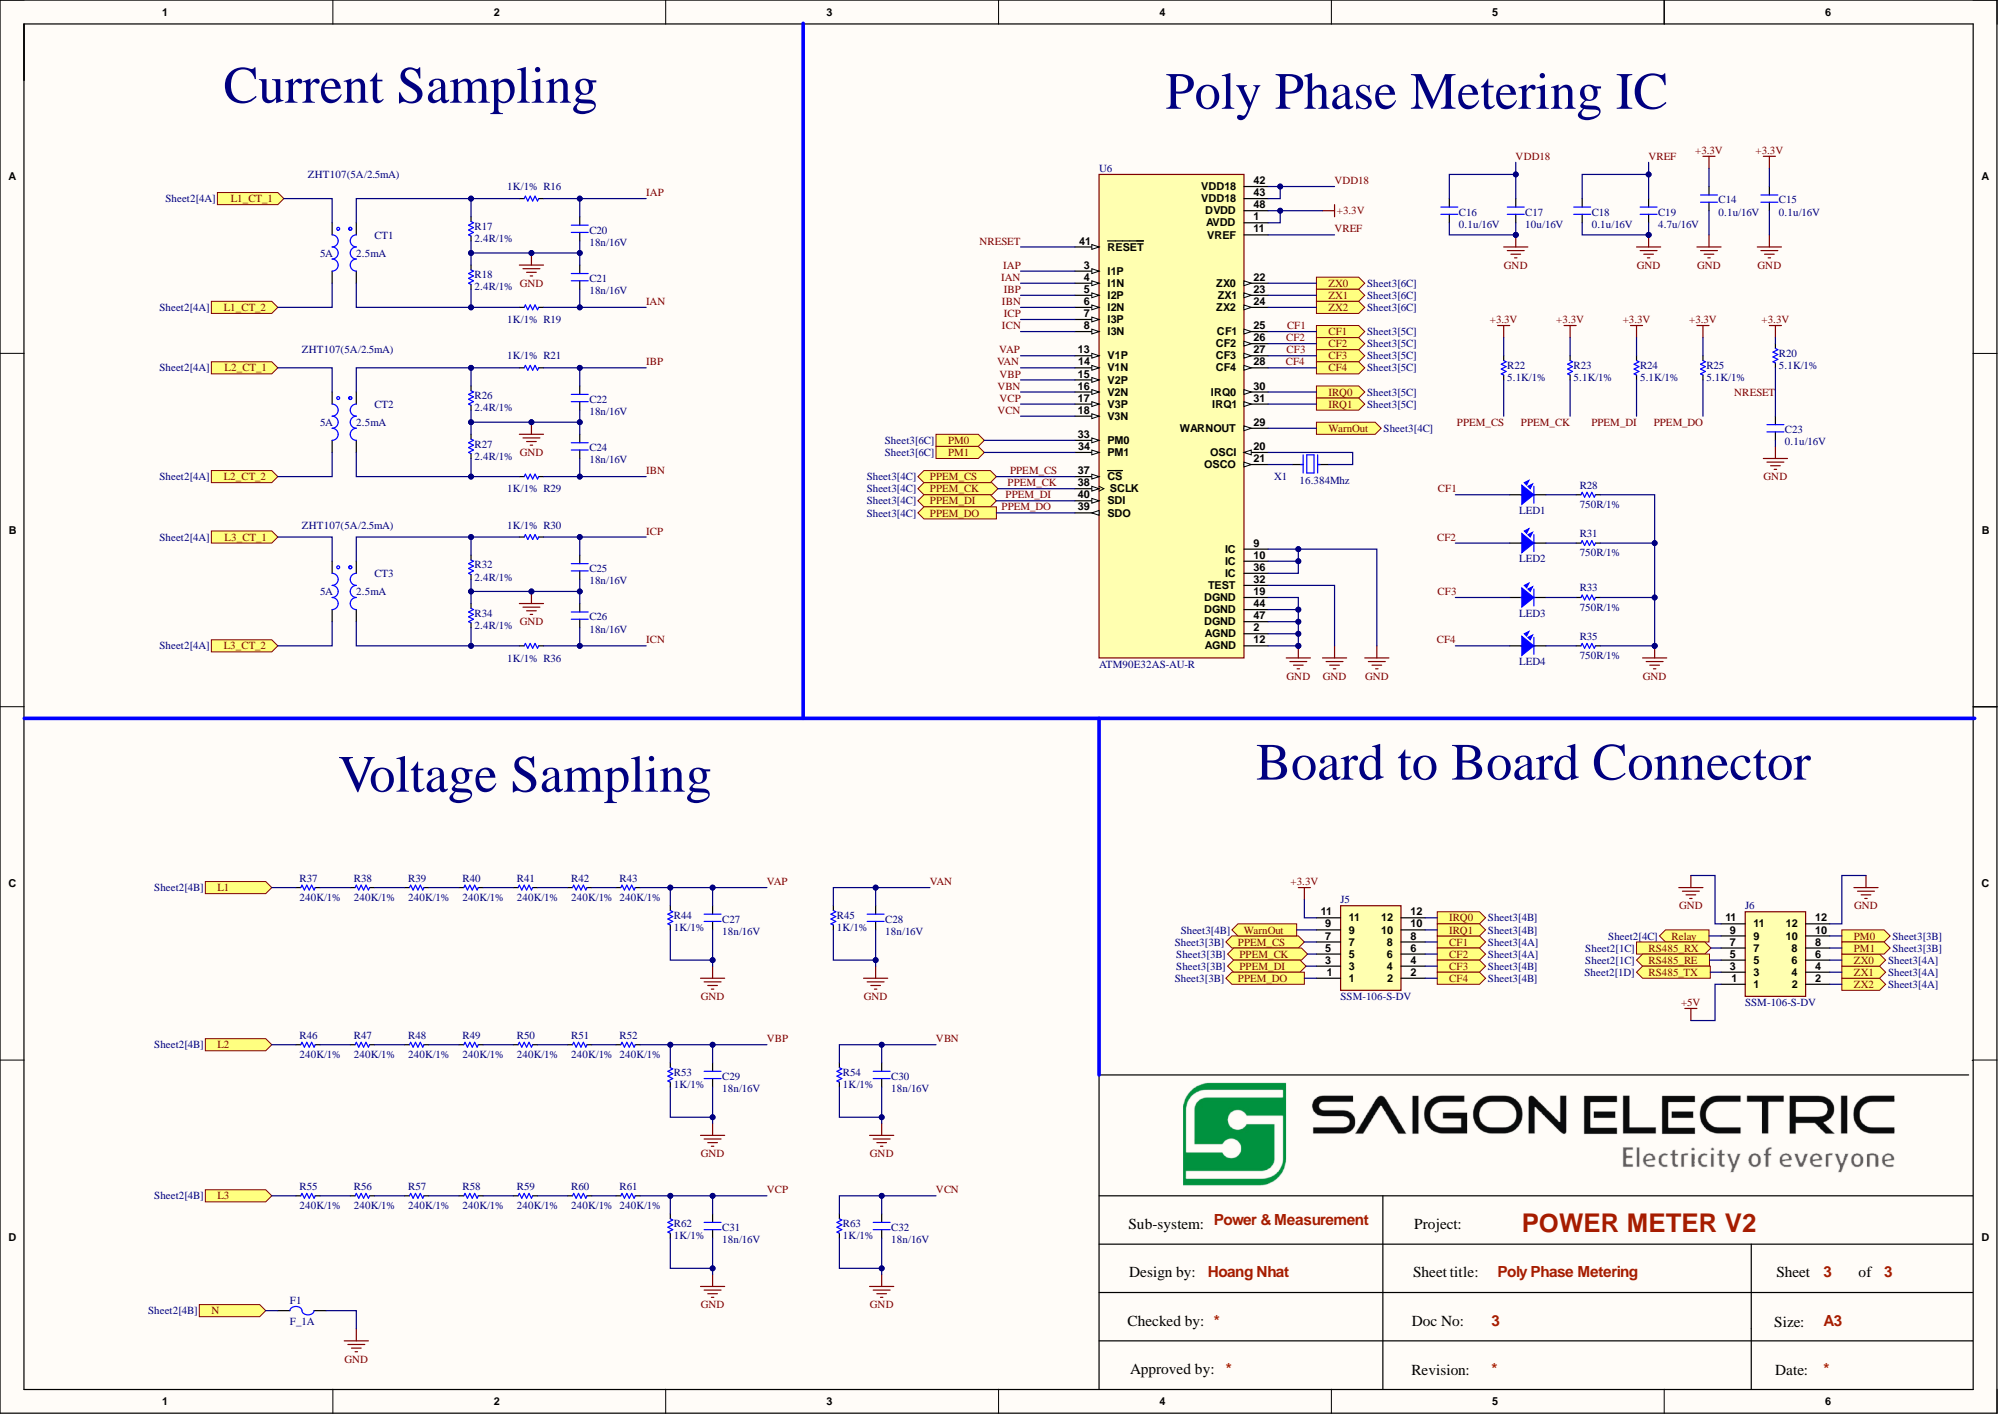
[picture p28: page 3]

Poly Phase Metering IC

GND
Board to Board Connector

Sub-system: Power & Measurement | Project: POWER METER V2

Design by: Hoang Nhat | Sheet title: Poly Phase Metering | Sheet 3 3 of
